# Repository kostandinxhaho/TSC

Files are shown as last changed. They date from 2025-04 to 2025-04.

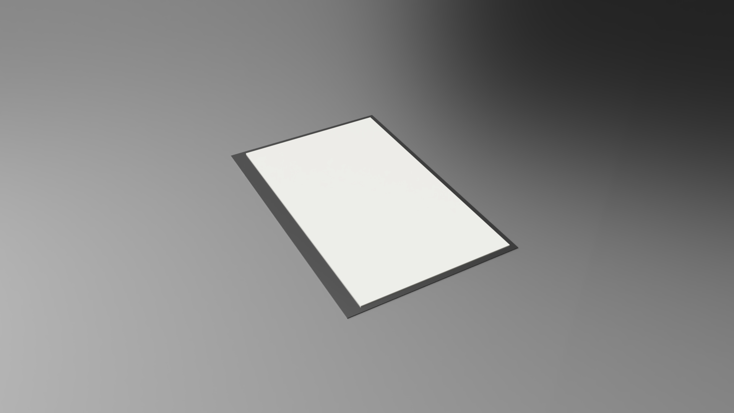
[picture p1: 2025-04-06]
Images/Screen_IMG.jpg

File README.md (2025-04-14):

# OpenBook eReader

This project is a minimalist eBook Reader called **OpenBook**, built around the ESP32-C6 platform. The device is contains:

  - **A 7.5-inch e-paper display**

  - **A Li-Po battery**

  - **USB-C charging**

  - **Navigation buttons**

The design focuses on energy efficiency and ease of use, featuring a simple interface managed via GPIOs. The primary goal is to provide an optimal e-reading experience with low power consumption and a comfortable display.

## System Overview

| **Component** | **Details** |
|---|---|
| **MCU** | ESP32-C6 – supports Wi-Fi 6, BLE, Zigbee, and Thread |
| **Display** | 7.5-inch E-Paper (800 x 480 resolution, ~44g) |
| **Sensors** | BME688 – measures gas, humidity, temperature, and pressure |
| **Storage** | External NOR Flash 64MB (SPI) <br> SD Card (SPI) for extra storage |
| **Power Supply** | Battery: CELLEVIA BATTERIES LP584174 (3.7V, 1800mAh) <br> LDO Voltage Regulator for a steady 3.3V |
| **RTC** | Real-Time Clock for keeping time even when powered off |
| **Charging** | MCP73831T – charges via USB-C |
| **Extras** | Test Pads for debugging <br> Qwiic interface for easy module expansion |

## Block Diagram



## Bill of Materials:
| **Component** | **Purchase Link** | **Datasheet Link** |
|---|---|---|
| 112A-TAAR-R03 ATTEND | [Buy on Digi-Key](https://www.digikey.com/en/products/detail/attend-technology/112A-TAAR-R03/17633923) | [Datasheet](https://www.snapeda.com/parts/112A-TAAR-R03/Attend/datasheet/) |
| BDS229G-TR | [Buy on Digi-Key](https://www.digikey.com/en/products/detail/rohm-semiconductor/BDS229G-TR/3663792) | [Datasheet](https://fscdn.rohm.com/en/products/databook/datasheet/ic/power/voltage_detector/bds229g-e.pdf) |
| ESP32 WROVER BME680 Sensor | [Buy on Mouser](https://www.mouser.com/ProductDetail/Bosch-Sensortec/BME680) | [Datasheet](https://www.bosch-sensortec.com/media/boschsensortec/downloads/datasheets/bst-bme680-ds001.pdf) |
| LED CHG_LED | [Buy on Mouser](https://www.mouser.com/ProductDetail/Wurth-Elektronik/150060SS75000) | [Datasheet](https://www.we-online.com/components/products/datasheet/150060SS75000.pdf) |
| Condensator C0402 | [Buy on Digi-Key](https://www.digikey.com/en/products/detail/murata-electronics/GRM155R71C104KA88D/675947) | [Datasheet](https://search.murata.co.jp/Ceramy/image/img/A01X/G101/ENG/GRM155R71C104KA88-01.pdf) |
| Condensator Tant | [Buy on Digi-Key](https://www.digikey.com/en/products/detail/kemet/T491A106K016AT/2336183) | [Datasheet](https://search.kemet.com/download/datasheet/T491A106K016AT) |
| Q1 DMG2305UX-7 | [Buy on Mouser](https://www.mouser.com/ProductDetail/Diodes-Incorporated/DMG2305UX-7) | [Datasheet](https://www.diodes.com/assets/Datasheets/DMG2305UX.pdf) |
| RTC MODULE DS3231SN# | [Buy on Digi-Key](https://www.digikey.com/en/products/detail/analog-devices-inc-maxim-integrated/DS3231SN/1197576) | [Datasheet](https://www.analog.com/media/en/technical-documentation/data-sheets/DS3231.pdf) |
| ESP32 C6 WROOM-1-N8 | [Buy on Digi-Key](https://www.digikey.com/en/products/detail/espressif-systems/ESP32-C6-WROOM-1-N8/17728866) | [Datasheet](https://www.espressif.com/sites/default/files/documentation/esp32-c6-wroom-1_wroom-1u_datasheet_en.pdf) |
| FH34SRJ-24S-0.5SH(99) | [Buy on Digi-Key](https://www.digikey.com/en/products/detail/hirose-electric-co-ltd/FH34SRJ-24S-0-5SH-99/5132529) | [Datasheet](https://www.hirose.com/product/p/CL0580-1255-6-99) |
| MAX17048G+T10 | [Buy on Mouser](https://www.mouser.com/ProductDetail/Analog-Devices/MAX17048G+T10) | [Datasheet](https://www.analog.com/media/en/technical-documentation/data-sheets/max17048-max17049.pdf) |
| MBR0530 Schottky Diode | [Buy on Mouser](https://www.mouser.com/ProductDetail/onsemi/MBR0530T1G) | [Datasheet](https://www.onsemi.com/pdf/datasheet/mbr0530t1-d.pdf) |
| ESP32 WROVER MCP73831 Power Management | [Buy on Adafruit](https://www.adafruit.com/product/4410) | [Datasheet](https://ww1.microchip.com/downloads/en/DeviceDoc/20001984g.pdf) |
| PFMF.050.1 | [Buy on Mouser](https://www.mouser.com/ProductDetail/Littelfuse/PFMF050-1) | [Datasheet](https://www.littelfuse.com/~/media/electrical/datasheets/resettable-ptcs/littelfuse_ptc_pfmf_datasheet.pdf) |
| PGB1010603MR | [Buy on Mouser](https://www.mouser.com/ProductDetail/Littelfuse/PGB1010603MR) | [Datasheet](https://www.littelfuse.com/~/media/electrical/datasheets/esd_suppressors/littelfuse_esd_supressor_pulse_guard_pgb0603.pdf) |
| QWIIC_RIGHT_ANGLE CONNECTOR | [Buy on SparkFun](https://www.sparkfun.com/products/14427) | [Datasheet](https://www.jst-mfg.com/product/pdf/eng/eSR.pdf) |
| Rezistență R0402 | [Buy on Mouser](https://www.mouser.com/c/passive-components/resistors/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) | [Datasheet](https://www.yageo.com/upload/media/product/product_search/datasheet/cpr/yageo-rc_series_datasheet_2018.pdf) |
| SD0805S020S1R0 | [Buy on Digi-Key](https://www.digikey.com/en/products/detail/littelfuse-inc/SD0805S020S1R0/736561) | [Datasheet](https://www.littelfuse.com/~/media/electrical/datasheets/resettable-ptcs/littelfuse_ptc_sd0805_series.pdf) |
| Si1308EDL-T1-GE3 MOSFET | [Buy on Mouser](https://www.mouser.com/ProductDetail/Vishay/SI1308EDL-T1-GE3) | [Datasheet](https://www.vishay.com/docs/63442/si1308edl.pdf) |
| USB4110-GF-A | [Buy on Mouser](https://www.mouser.com/ProductDetail/GCT/USB4110-GF-A) | [Datasheet](https://gct.co/drawings/usb4110.pdf) |
| USBLC6-2SC6Y | [Buy on Mouser](https://www.mouser.com/ProductDetail/STMicroelectronics/USBLC6-2SC6Y) | [Datasheet](https://www.st.com/resource/en/datasheet/usblc6-2sc6.pdf) |
| W25Q512JVEIQ | [Buy on Mouser](https://www.mouser.com/ProductDetail/Winbond/W25Q512JVEIQ) | [Datasheet](https://www.winbond.com/resource-files/w25q512jv%20revg%2011022019%20plus.pdf) |
| XC6220A331MR-G | [Buy on Digi-Key](https://www.digikey.com/en/products/detail/torex-semiconductor-ltd/XC6220A331MR-G/5027707) | [Datasheet](https://www.torexsemi.com/file/xc6220/XC6220.pdf) |
| 744043680 BOBINA | [Buy on Mouser](https://www.mouser.com/ProductDetail/Wurth-Elektronik/744043680) | [Datasheet](https://katalog.we-online.com/pbs/datasheet/744043680.pdf) |

## Power Supply & Battery Management

The system supports dual power sources:

- **USB-C (5V) input**
- **3.7V Li-Po battery (CELLEVIA LP584174, 1800mAh)**

Power is managed as follows:

- **MCP73831** – Charges the Li-Po battery when USB-C is connected
- **LDO Voltage Regulator** – Converts 5V USB input to 3.3V

##  Sensors & Real-Time Clock (RTC)

Connected via the I²C bus:

- **BME688** – Measures temperature, humidity, pressure, and VOCs
- **DS3231** – High-precision RTC with battery backup

Sensor readings are processed locally and can be used for both display and logging.

## E-Paper Display

The **7.5-inch E-Ink display** interfaces over SPI and is controlled using:

- `EPD_CS` – Chip Select  
- `EPD_DC` – Data/Command  
- `EPD_RST` – Reset  
- `EPD_BUSY` – Busy indicator

The display only consumes energy when refreshing. Once the image is rendered, it holds static content without any power draw — perfect for long battery life.

## ESP32-C6 Connection

The following table shows the core hardware connections between the ESP32-C6 and its peripherals, organized by function:

| **Function** | **ESP32-C6 Pins** |
|---|---|
| **Power & Reset** | 3V3, GND, EN |
| **USB-C** | GPIO13 (USB_D+), GPIO14 (USB_D−) |
| **SD Card (SPI)** | GPIO27 (MISO), GPIO7 (MOSI), GPIO6 (SCK), GPIO4 (SS_SD) |
| **E-Paper Display**  | GPIO11 (EPD_CS), GPIO5 (EPD_DC), GPIO21 (EPD_RST), GPIO26 (EPD_BUSY) |
| **BME688 Sensor (I²C)** | GPIO19 (SDA), GPIO20 (SCL), GPIO17 (I2C_PWR) |
| **UART** | TXD0, RXD0 |
| **External Flash** | FLASH_CS |
| **Other Functions**  | IO/BOOT, RTC_PWM, RTC_RST, INT_RTC |

## Communication Interfaces

- **SPI Bus**: Used by the E-Paper display, external Flash, and SD card. Each device has its own **chip select (CS)** pin to avoid conflicts.
- **I²C Bus**: Shared among BME688, RTC, and battery monitoring. Devices are addressable and use internal pull-ups for signal integrity.
- **UART**: Reserved for programming and serial monitoring via USB.
- **GPIOs**: Dedicated for user interaction (buttons, interrupts) or reserved for future extension.

## The project realization process

- Firstly I built the schematic using the model given in OCW, for the PCB model I followed the scheme respecting the given parameters.
- I created the ground planes with the GND signal on the top and bottom.
- Autorooted the paths, made the cables 0.3mm and 1.5mm respectively. Here I had to keep 1 of the cables the default size of 1.27 because it would create a lot of errors. (AIRCABLE)
- Made the battery and screen 3d models respecting the given parameters. Rendernd all the 3d models and the whole of them combined.

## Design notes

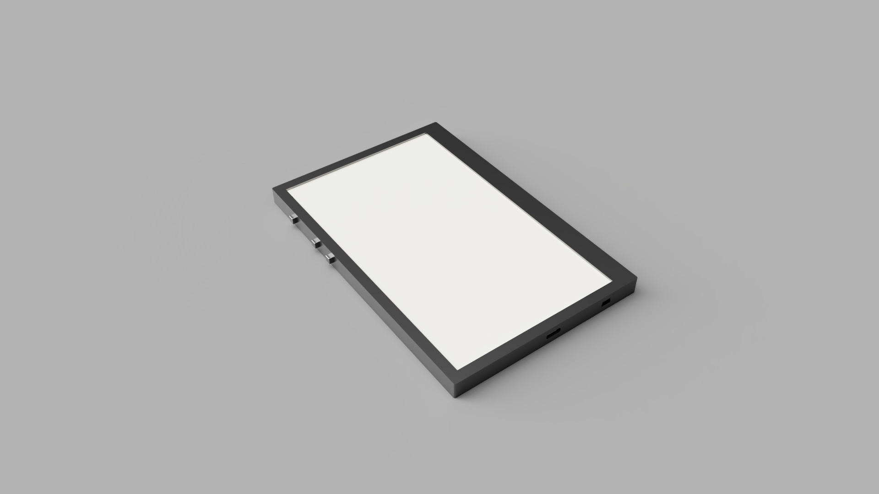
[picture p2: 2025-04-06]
Images/OpenBook_IMG.jpg

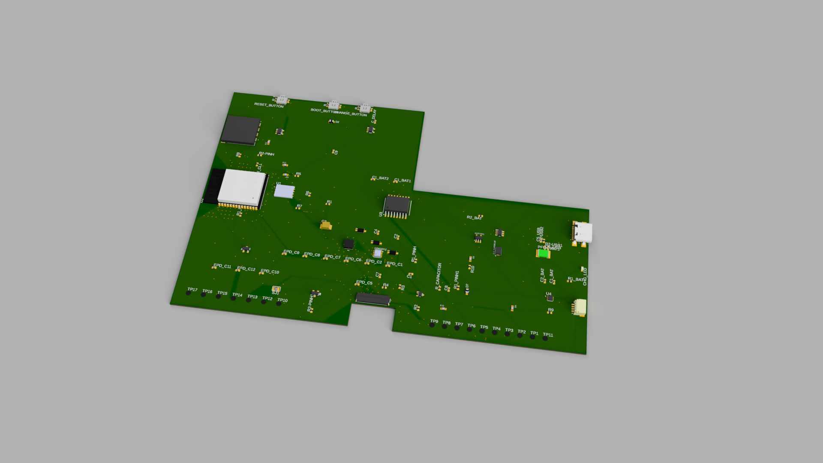
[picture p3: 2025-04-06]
Images/PCB_3D_IMG.jpg

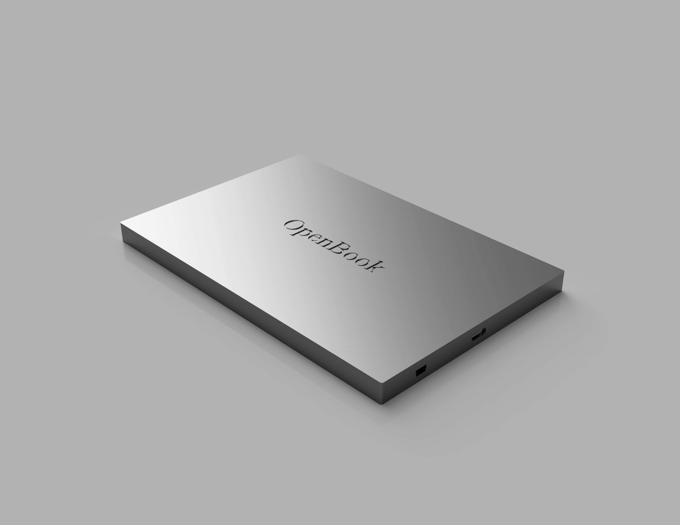
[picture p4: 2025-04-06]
Images/OpenBook_IMG_v2.jpg

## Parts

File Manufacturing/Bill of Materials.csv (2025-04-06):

Part | Value | Device | Package | Description
BOOT_BUTTON | BUTTON_CUSYOMV1 | BUTTON_CUSYOMV1 | MYBUTTON
C1 | 100nF | ESP32_WROVER_EAGLE-LTSPICE_CC0402 | ESP32_WROVER_EAGLE-LTSPICE_C0402 | CAPACITOR, European symbol
C1_BAT | 4.7uF | ESP32_WROVER_EAGLE-LTSPICE_CC0402 | ESP32_WROVER_EAGLE-LTSPICE_C0402 | CAPACITOR, European symbol
C1_BAT1 | 4.7uF | ESP32_WROVER_EAGLE-LTSPICE_CC0402 | ESP32_WROVER_EAGLE-LTSPICE_C0402 | CAPACITOR, European symbol
C1_BAT2 | 4.7uF | ESP32_WROVER_EAGLE-LTSPICE_CC0402 | ESP32_WROVER_EAGLE-LTSPICE_C0402 | CAPACITOR, European symbol
C2 | 100nF | ESP32_WROVER_EAGLE-LTSPICE_CC0402 | ESP32_WROVER_EAGLE-LTSPICE_C0402 | CAPACITOR, European symbol
C2_BAT | 4.7uF | ESP32_WROVER_EAGLE-LTSPICE_CC0402 | ESP32_WROVER_EAGLE-LTSPICE_C0402 | CAPACITOR, European symbol
C3 | 100uF TANT | RCL_CPOL-EUCT3528 | RCL_CT3528 | POLARIZED CAPACITOR, European symbol
C4 | 4.7uF/25V | EAGLE-LTSPICE_CC0402 | EAGLE-LTSPICE_C0402 | CAPACITOR, European symbol
C4_USB | 100nF | EAGLE-LTSPICE_CC0402 | EAGLE-LTSPICE_C0402 | CAPACITOR, European symbol
C5 | 1uF | ESP32_WROVER_EAGLE-LTSPICE_CC0402 | ESP32_WROVER_EAGLE-LTSPICE_C0402 | CAPACITOR, European symbol
C5_USB | 4.7uF | EAGLE-LTSPICE_CC0402 | EAGLE-LTSPICE_C0402 | CAPACITOR, European symbol
C6 | 100nF | ESP32_WROVER_EAGLE-LTSPICE_CC0402 | ESP32_WROVER_EAGLE-LTSPICE_C0402 | CAPACITOR, European symbol
C7 | 10uF | ESP32_WROVER_EAGLE-LTSPICE_CC0402 | ESP32_WROVER_EAGLE-LTSPICE_C0402 | CAPACITOR, European symbol
C8 | 100nF | ESP32_WROVER_EAGLE-LTSPICE_CC0402 | ESP32_WROVER_EAGLE-LTSPICE_C0402 | CAPACITOR, European symbol
C9 | 100nF | ESP32_WROVER_EAGLE-LTSPICE_CC0402 | ESP32_WROVER_EAGLE-LTSPICE_C0402 | CAPACITOR, European symbol
C10 | 100nF | ESP32_WROVER_EAGLE-LTSPICE_CC0402 | ESP32_WROVER_EAGLE-LTSPICE_C0402 | CAPACITOR, European symbol
C10_SUPERCAP | CPH3225A | CPH3225A | CAPCP3225X100N | Cap 0.011F 3.3V 1210 Flat Check availability
CHANGE_BUTTON | BUTTON_CUSYOMV1 | BUTTON_CUSYOMV1 | MYBUTTON
CHG_LED |  | ADAFRUIT_LEDCHIP-LED0603 | ADAFRUIT_CHIP-LED0603 | LED
C_DELAY | 100nF | ESP32_WROVER_EAGLE-LTSPICE_CC0402 | ESP32_WROVER_EAGLE-LTSPICE_C0402 | CAPACITOR, European symbol
D1 | USBLC6-2SC6Y | USBLC6-2SC6Y | SOT95P280X145-6N | Low Cap. ESD Protection Auto SOT-23-6 STMicroelectronics USBLC6-2SC6Y, Dual Uni-Directional TVS Diode Array, 6-Pin SOT-23
D2 | ESP32_WROVER_AVX---SD0805S020S1R0_AVX_SD0805S020S1R0_0_0AVX_SD0805S020S1R0_0_0 | ESP32_WROVER_AVX---SD0805S020S1R0_AVX_SD0805S020S1R0_0_0AVX_SD0805S020S1R0_0_0 | ESP32_WROVER_AVX---SD0805S020S1R0_AVX_SD0805S020S1R0_0 | Schottky Barrier Rectifier Diode
D3 | MBR0530 | MBR0530 | SOD3716X135N | ON SEMICONDUCTOR - MBR0530 - DIODE, SCHOTTKY, 0.5A, 30V, SOD-123
D4 | MBR0530 | MBR0530 | SOD3716X135N | ON SEMICONDUCTOR - MBR0530 - DIODE, SCHOTTKY, 0.5A, 30V, SOD-123
D5 | MBR0530 | MBR0530 | SOD3716X135N | ON SEMICONDUCTOR - MBR0530 - DIODE, SCHOTTKY, 0.5A, 30V, SOD-123
D6 | PGB1010603MR | PGB1010603MR | DIOC1608X36N | Check availability
D7 | ESP32_WROVER_AVX---SD0805S020S1R0_AVX_SD0805S020S1R0_0_0AVX_SD0805S020S1R0_0_0 | ESP32_WROVER_AVX---SD0805S020S1R0_AVX_SD0805S020S1R0_0_0AVX_SD0805S020S1R0_0_0 | ESP32_WROVER_AVX---SD0805S020S1R0_AVX_SD0805S020S1R0_0 | Schottky Barrier Rectifier Diode
D8 | PGB1010603MR | PGB1010603MR | DIOC1608X36N | Check availability
D9 | PGB1010603MR | PGB1010603MR | DIOC1608X36N | Check availability
D10 | PGB1010603MR | PGB1010603MR | DIOC1608X36N | Check availability
D11 | PGB1010603MR | PGB1010603MR | DIOC1608X36N | Check availability
D12 | PGB1010603MR | PGB1010603MR | DIOC1608X36N | Check availability
EPD_C1 | 1uF/50V | ESP32_WROVER_EAGLE-LTSPICE_CC0402 | ESP32_WROVER_EAGLE-LTSPICE_C0402 | CAPACITOR, European symbol
EPD_C2 | 1uF/50V | ESP32_WROVER_EAGLE-LTSPICE_CC0402 | ESP32_WROVER_EAGLE-LTSPICE_C0402 | CAPACITOR, European symbol
EPD_C5 | 0.1uF/50V | ESP32_WROVER_EAGLE-LTSPICE_CC0402 | ESP32_WROVER_EAGLE-LTSPICE_C0402 | CAPACITOR, European symbol
EPD_C6 | 1uF/50V | ESP32_WROVER_EAGLE-LTSPICE_CC0402 | ESP32_WROVER_EAGLE-LTSPICE_C0402 | CAPACITOR, European symbol
EPD_C7 | 1uF/50V | ESP32_WROVER_EAGLE-LTSPICE_CC0402 | ESP32_WROVER_EAGLE-LTSPICE_C0402 | CAPACITOR, European symbol
EPD_C8 | 1uF/50V | ESP32_WROVER_EAGLE-LTSPICE_CC0402 | ESP32_WROVER_EAGLE-LTSPICE_C0402 | CAPACITOR, European symbol
EPD_C9 | 1uF/50V | ESP32_WROVER_EAGLE-LTSPICE_CC0402 | ESP32_WROVER_EAGLE-LTSPICE_C0402 | CAPACITOR, European symbol
EPD_C10 | 1uF/50V | ESP32_WROVER_EAGLE-LTSPICE_CC0402 | ESP32_WROVER_EAGLE-LTSPICE_C0402 | CAPACITOR, European symbol
EPD_C11 | 1uF/50V | ESP32_WROVER_EAGLE-LTSPICE_CC0402 | ESP32_WROVER_EAGLE-LTSPICE_C0402 | CAPACITOR, European symbol
EPD_C12 | 1uF/50V | ESP32_WROVER_EAGLE-LTSPICE_CC0402 | ESP32_WROVER_EAGLE-LTSPICE_C0402 | CAPACITOR, European symbol
IC1 | BD5229G-TR | BD5229G-TR | SOT95P280X125-5N | Voltage Detector with Adjustable Delay Time: CMOS processes are utilized to develop high precision, low current consumption CMOS reset ICs that allow arbitrary setting of the delay time. The extensive lineup includes both Nch Open Drain and CMOS output types in a wide range of detection voltages (from 2.3V to 6.0V, in 0.1V steps), enabling selection of the ideal solution based on customer requirements. In addition, the entire series is of course both lead-free and RoHS-compliant.
IC4 | XC6220A331MR-G | XC6220A331MR-G | SOT95P280X120-5N | LDO Voltage Regulators
J1 | FH34SRJ-24S-0.5SH_99_ | FH34SRJ-24S-0.5SH_99_ | FH34SRJ24S05SH99 | (0.50mm) Surface Mount, Right Angle
J2 | SAMACSYS_PARTS_USB4110-GF-A | SAMACSYS_PARTS_USB4110-GF-A | SAMACSYS_PARTS_USB4110GFA | CONN USB 2.0 TYPE-C R/A SMT
J3 | QWIIC_RIGHT_ANGLE | QWIIC_CONNECTORJS-1MM | JST04_1MM_RA | SparkFun I2C Standard Qwiic Connector
J4 | 112A-TAAR-R03_ATTEND | 112A-TAAR-R03_ATTEND | 112ATAARR03ATTEND | Micro SD Card Socket, Push-Push Type, Top Mount, SMT, H=1.83mm, 10u
L1 | 68uH | 744043680IND_4828-WE-TPC_WRE | IND_4828-WE-TPC_WRE
MCP73831 | ESP32_WROVER_SPARKFUN-IC-POWER_MCP73831 | ESP32_WROVER_SPARKFUN-IC-POWER_MCP73831 | ESP32_WROVER_SPARKFUN-IC-POWER_SOT23-5 | MCP73831T Li-Ion, Li-Pol Controller
PFMF.050.1 | ESP32C6_VARISTORCN1812 | ESP32C6_VARISTORCN1812 | ESP32C6_VARISTOR_CT/CN1812 | VARISTOR
Q1 | 20V/4.2A/52mO/1.4W | ESP32_WROVER_SPARKFUN-DISCRETESEMI_MOSFET_PCH-DMG2305UX-7 | ESP32_WROVER_SPARKFUN-DISCRETESEMI_SOT23-3 | P-channel MOSFETs
Q2 | 20V/4.2A/52mO/1.4W | ESP32_WROVER_SPARKFUN-DISCRETESEMI_MOSFET_PCH-DMG2305UX-7 | ESP32_WROVER_SPARKFUN-DISCRETESEMI_SOT23-3 | P-channel MOSFETs
Q3 | SI1308EDL-T1-GE3 | SI1308EDL-T1-GE3 | SOT65P210X110-3N | MOSFET N-Ch 30V 1.5A TrenchFET SC70 Vishay Si1308EDL-T1-GE3 N-channel MOSFET Transistor, 1.5 A, 30 V, 3-Pin SC-70
R1 | 10K | ESP32_WROVER_EAGLE-LTSPICE_RR0402 | ESP32_WROVER_EAGLE-LTSPICE_R0402 | RESISTOR, European symbol
R1_BAT | 200 | ESP32_WROVER_EAGLE-LTSPICE_RR0402 | ESP32_WROVER_EAGLE-LTSPICE_R0402 | RESISTOR, European symbol
R1_PINH | 10K | ESP32_WROVER_EAGLE-LTSPICE_RR0402 | ESP32_WROVER_EAGLE-LTSPICE_R0402 | RESISTOR, European symbol
R1_PINH1 | 10K | ESP32_WROVER_EAGLE-LTSPICE_RR0402 | ESP32_WROVER_EAGLE-LTSPICE_R0402 | RESISTOR, European symbol
R1_PWRUSB | 100K | ESP32_WROVER_EAGLE-LTSPICE_RR0402 | ESP32_WROVER_EAGLE-LTSPICE_R0402 | RESISTOR, European symbol
R2 | 2.2 | ESP32_WROVER_EAGLE-LTSPICE_RR0402 | ESP32_WROVER_EAGLE-LTSPICE_R0402 | RESISTOR, European symbol
R2-PINH | 10K | ESP32_WROVER_EAGLE-LTSPICE_RR0402 | ESP32_WROVER_EAGLE-LTSPICE_R0402 | RESISTOR, European symbol
R2-PINH1 | 10K | ESP32_WROVER_EAGLE-LTSPICE_RR0402 | ESP32_WROVER_EAGLE-LTSPICE_R0402 | RESISTOR, European symbol
R2-USB1 | 5k1 | ESP32_WROVER_EAGLE-LTSPICE_RR0402 | ESP32_WROVER_EAGLE-LTSPICE_R0402 | RESISTOR, European symbol
R2-USB2 | 5k1 | ESP32_WROVER_EAGLE-LTSPICE_RR0402 | ESP32_WROVER_EAGLE-LTSPICE_R0402 | RESISTOR, European symbol
R2_BAT | 2K | ESP32_WROVER_EAGLE-LTSPICE_RR0402 | ESP32_WROVER_EAGLE-LTSPICE_R0402 | RESISTOR, European symbol
R3 | 0.47 | ESP32_WROVER_EAGLE-LTSPICE_RR0402 | ESP32_WROVER_EAGLE-LTSPICE_R0402 | RESISTOR, European symbol
R4 | 10K | ESP32_WROVER_EAGLE-LTSPICE_RR0402 | ESP32_WROVER_EAGLE-LTSPICE_R0402 | RESISTOR, European symbol
R5 | 10K | ESP32_WROVER_EAGLE-LTSPICE_RR0402 | ESP32_WROVER_EAGLE-LTSPICE_R0402 | RESISTOR, European symbol
R6 | 10K | ESP32_WROVER_EAGLE-LTSPICE_RR0402 | ESP32_WROVER_EAGLE-LTSPICE_R0402 | RESISTOR, European symbol
R7 | 10K | ESP32_WROVER_EAGLE-LTSPICE_RR0402 | ESP32_WROVER_EAGLE-LTSPICE_R0402 | RESISTOR, European symbol
R8 | 10K | ESP32_WROVER_EAGLE-LTSPICE_RR0402 | ESP32_WROVER_EAGLE-LTSPICE_R0402 | RESISTOR, European symbol
R9 | 10K | ESP32_WROVER_EAGLE-LTSPICE_RR0402 | ESP32_WROVER_EAGLE-LTSPICE_R0402 | RESISTOR, European symbol
R10 | 10K | ESP32_WROVER_EAGLE-LTSPICE_RR0402 | ESP32_WROVER_EAGLE-LTSPICE_R0402 | RESISTOR, European symbol
RESET_BUTTON | BUTTON_CUSYOMV1 | BUTTON_CUSYOMV1 | MYBUTTON
R_BOOT | 10K | ESP32_WROVER_EAGLE-LTSPICE_RR0402 | ESP32_WROVER_EAGLE-LTSPICE_R0402 | RESISTOR, European symbol
R_CAPACITOR | 15 | ESP32_WROVER_EAGLE-LTSPICE_RR0402 | ESP32_WROVER_EAGLE-LTSPICE_R0402 | RESISTOR, European symbol
R_CHANGE | 10K | ESP32_WROVER_EAGLE-LTSPICE_RR0402 | ESP32_WROVER_EAGLE-LTSPICE_R0402 | RESISTOR, European symbol
R_CL1 | 10K | ESP32_WROVER_EAGLE-LTSPICE_RR0402 | ESP32_WROVER_EAGLE-LTSPICE_R0402 | RESISTOR, European symbol
R_RESET | 10K | ESP32_WROVER_EAGLE-LTSPICE_RR0402 | ESP32_WROVER_EAGLE-LTSPICE_R0402 | RESISTOR, European symbol
SENSOR2 | BME688 | ESP32_WROVER_BME680_BME680 | ESP32_WROVER_BME680_PSON80P300X300X100-8N | Integrated Environmental Unit
SJ1 |  | SJ | SJ | SMD solder JUMPER
TP1 | TPTP20R | TPTP20R | TP20R | Test pad
TP2 | TPTP20R | TPTP20R | TP20R | Test pad
TP3 | TPTP20R | TPTP20R | TP20R | Test pad
TP4 | TPTP20R | TPTP20R | TP20R | Test pad
TP5 | TPTP20R | TPTP20R | TP20R | Test pad
TP6 | TPTP20R | TPTP20R | TP20R | Test pad
TP7 | TPTP20R | TPTP20R | TP20R | Test pad
TP8 | TPTP20R | TPTP20R | TP20R | Test pad
TP9 | TPTP20R | TPTP20R | TP20R | Test pad
TP10 | TPTP20R | TPTP20R | TP20R | Test pad
TP11 | TPTP20R | TPTP20R | TP20R | Test pad
TP12 | TPTP20R | TPTP20R | TP20R | Test pad
TP13 | TPTP20R | TPTP20R | TP20R | Test pad
TP14 | TPTP20R | TPTP20R | TP20R | Test pad
TP15 | TPTP20R | TPTP20R | TP20R | Test pad
TP16 | TPTP20R | TPTP20R | TP20R | Test pad
TP17 | TPTP20R | TPTP20R | TP20R | Test pad
U1 | W25Q512JVEIQ | W25Q512JVEIQ | SON127P600X800X80-9N | Check availability
U2 | ESP32-C6-WROOM-1-N8 | ESP32-C6-WROOM-1-N8 | XCVR_ESP32-C6-WROOM-1-N8 | Check availability
U3 | DS3231SN# | DS3231SN# | SOIC127P1032X265-16N | Real Time Clock Serial 16-Pin SOIC W T/R Check availability
U4 | MAX17048G+T10 | MAX17048G+T10 | SON50P200X200X80-9N | Check availability

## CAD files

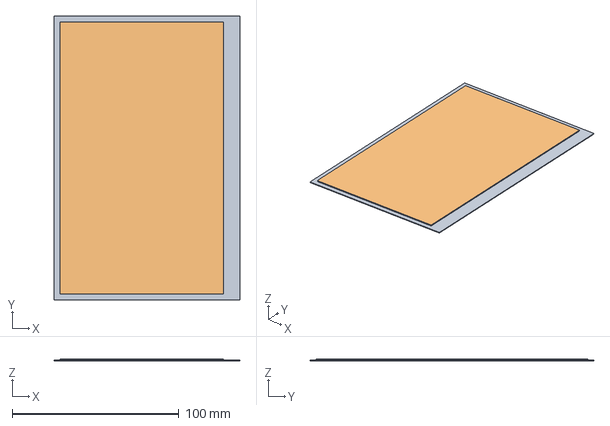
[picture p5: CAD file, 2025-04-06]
Mechanical/Screen.step
111.2 x 170.2 x 1.18 mm

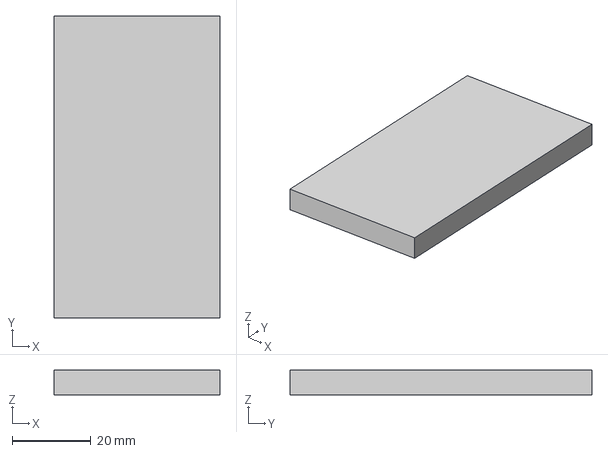
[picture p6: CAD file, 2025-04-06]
Mechanical/Battery.step
42.0 x 76.5 x 6.30 mm

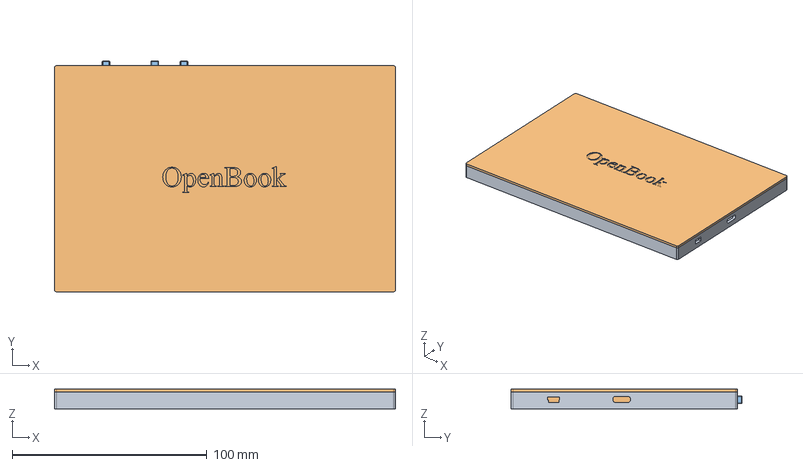
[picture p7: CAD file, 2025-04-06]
Mechanical/OpenBook_case.step
175.2 x 118.5 x 10.2 mm

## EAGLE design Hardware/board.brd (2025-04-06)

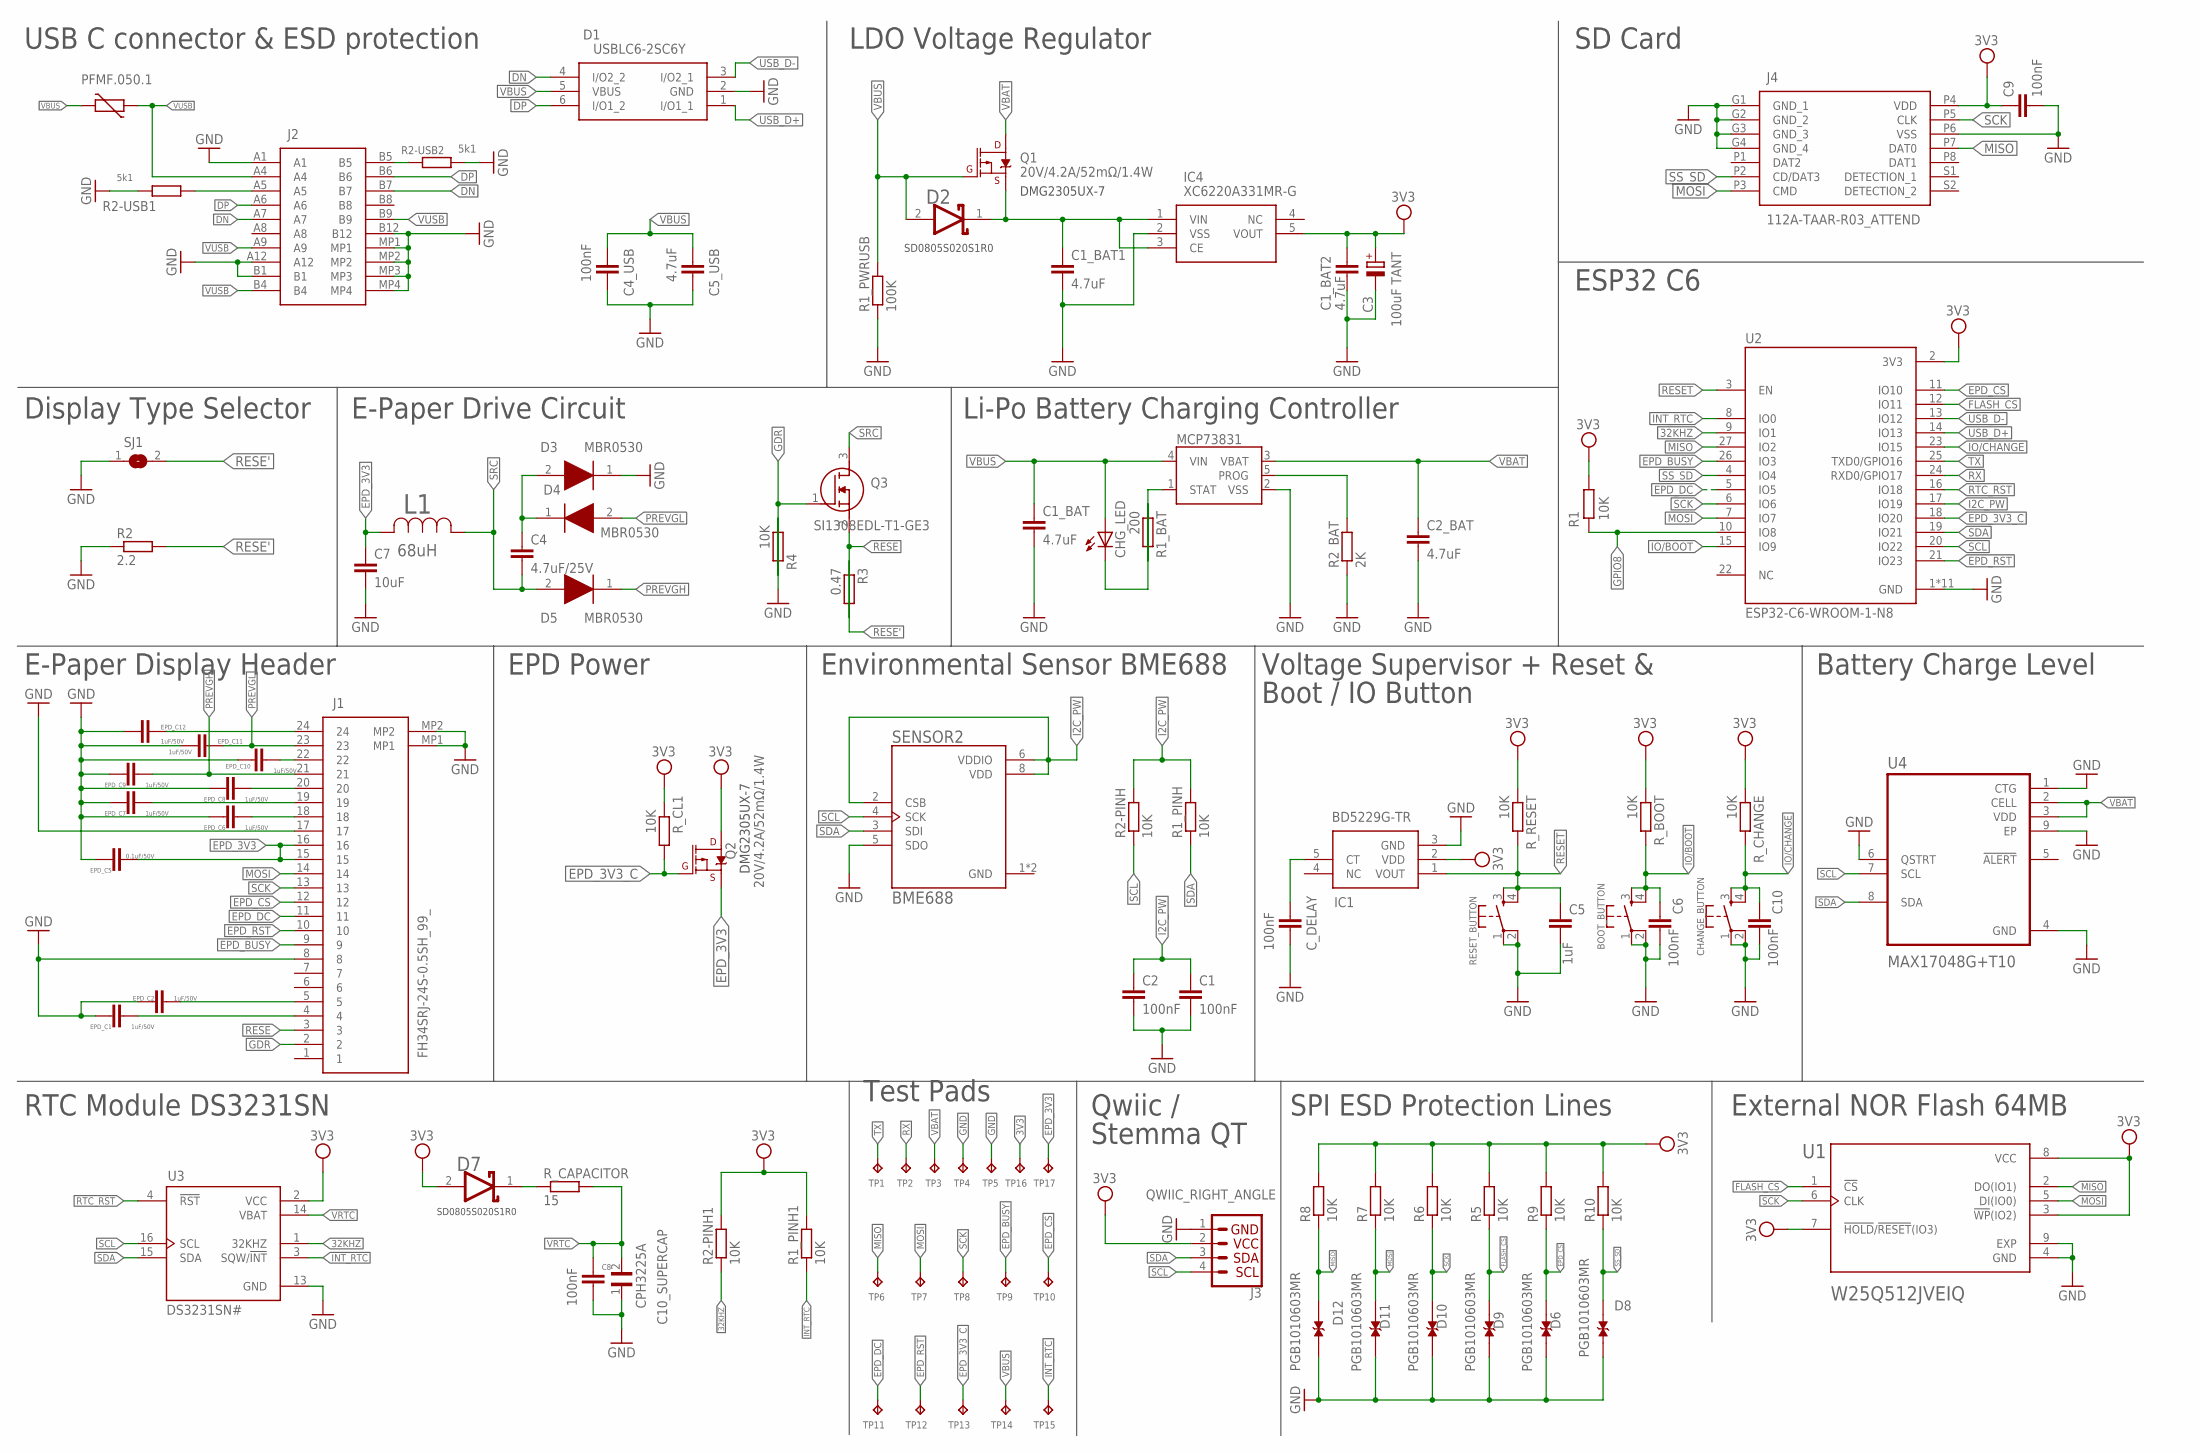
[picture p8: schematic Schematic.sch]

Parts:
BOOT_BUTTON: BUTTON_CUSYOMV1; MYBUTTON
C1, C2, C6, C8, C9, C10: 100nF; ESP32_WROVER_EAGLE-LTSPICE_C0402
C1_BAT, C1_BAT1, C1_BAT2, C2_BAT: 4.7uF; ESP32_WROVER_EAGLE-LTSPICE_C0402
C3: 100uF TANT; RCL_CT3528
C4: 4.7uF/25V; EAGLE-LTSPICE_C0402
C4_USB: 100nF; EAGLE-LTSPICE_C0402
C5: 1uF; ESP32_WROVER_EAGLE-LTSPICE_C0402
C5_USB: 4.7uF; EAGLE-LTSPICE_C0402
C7: 10uF; ESP32_WROVER_EAGLE-LTSPICE_C0402
C10_SUPERCAP: CPH3225A; CAPCP3225X100N
CHANGE_BUTTON: BUTTON_CUSYOMV1; MYBUTTON
CHG_LED: ADAFRUIT_LEDCHIP-LED0603; ADAFRUIT_CHIP-LED0603
C_DELAY: 100nF; ESP32_WROVER_EAGLE-LTSPICE_C0402
D1: USBLC6-2SC6Y; SOT95P280X145-6N
D2, D7: ESP32_WROVER_AVX---SD0805S020S1R0_AVX_SD0805S020S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; ESP32_WROVER_AVX---SD0805S020S1R0_AVX_SD0805S020S1R0_0
D3, D4, D5: MBR0530; SOD3716X135N
D6, D8, D9, D10, D11, D12: PGB1010603MR; DIOC1608X36N
EPD_C1, EPD_C2, EPD_C6, EPD_C7, EPD_C8, EPD_C9, EPD_C10, EPD_C11, EPD_C12: 1uF/50V; ESP32_WROVER_EAGLE-LTSPICE_C0402
EPD_C5: 0.1uF/50V; ESP32_WROVER_EAGLE-LTSPICE_C0402
IC1: BD5229G-TR; SOT95P280X125-5N
IC4: XC6220A331MR-G; SOT95P280X120-5N
J1: FH34SRJ-24S-0.5SH_99_; FH34SRJ24S05SH99
J2: SAMACSYS_PARTS_USB4110-GF-A; SAMACSYS_PARTS_USB4110GFA
J3: QWIIC_RIGHT_ANGLE; JST04_1MM_RA
J4: 112A-TAAR-R03_ATTEND; 112ATAARR03ATTEND
L1: 68uH; IND_4828-WE-TPC_WRE
MCP73831: ESP32_WROVER_SPARKFUN-IC-POWER_MCP73831; ESP32_WROVER_SPARKFUN-IC-POWER_SOT23-5
PFMF.050.1: ESP32C6_VARISTORCN1812; ESP32C6_VARISTOR_CT/CN1812
Q1, Q2: 20V/4.2A/52mΩ/1.4W; ESP32_WROVER_SPARKFUN-DISCRETESEMI_SOT23-3
Q3: SI1308EDL-T1-GE3; SOT65P210X110-3N
R1, R1_PINH, R1_PINH1, R2-PINH, R2-PINH1, R4, R5, R6, R7, R8, R9, R10: 10K; ESP32_WROVER_EAGLE-LTSPICE_R0402
R1_BAT: 200; ESP32_WROVER_EAGLE-LTSPICE_R0402
R1_PWRUSB: 100K; ESP32_WROVER_EAGLE-LTSPICE_R0402
R2: 2.2; ESP32_WROVER_EAGLE-LTSPICE_R0402
R2-USB1, R2-USB2: 5k1; ESP32_WROVER_EAGLE-LTSPICE_R0402
R2_BAT: 2K; ESP32_WROVER_EAGLE-LTSPICE_R0402
R3: 0.47; ESP32_WROVER_EAGLE-LTSPICE_R0402
RESET_BUTTON: BUTTON_CUSYOMV1; MYBUTTON
R_BOOT: 10K; ESP32_WROVER_EAGLE-LTSPICE_R0402
R_CAPACITOR: 15; ESP32_WROVER_EAGLE-LTSPICE_R0402
R_CHANGE: 10K; ESP32_WROVER_EAGLE-LTSPICE_R0402
R_CL1: 10K; ESP32_WROVER_EAGLE-LTSPICE_R0402
R_RESET: 10K; ESP32_WROVER_EAGLE-LTSPICE_R0402
SENSOR2: BME688; ESP32_WROVER_BME680_PSON80P300X300X100-8N
SJ1: SJ
TP1, TP2, TP3, TP4, TP5, TP6, TP7, TP8, TP9, TP10, TP11, TP12, TP13, TP14, TP15, TP16, TP17: TPTP20R; TP20R
U1: W25Q512JVEIQ; SON127P600X800X80-9N
U2: ESP32-C6-WROOM-1-N8; XCVR_ESP32-C6-WROOM-1-N8
U3: DS3231SN#; SOIC127P1032X265-16N
U4: MAX17048G+T10; SON50P200X200X80-9N

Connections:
3V3: C1_BAT2.1, C3.+, C9.1, D7.2 (ANODE), IC1.2 (VDD), IC4.5 (VOUT), J3.2, J4.P4 (VDD), Q2.3 (D), R1.1, R1_PINH1.2, R2-PINH1.2, R5.2, R6.2, R7.2, R8.2, R9.2, R10.2, R_BOOT.1, R_CHANGE.1, R_CL1.1, R_RESET.1, TP16.TP, U1.3 (!WP!(IO2)), U1.7 (!HOLD!/!RESET!(IO3)), U1.8 (VCC), U2.2 (3V3), U3.2 (VCC)
32KHZ: R2-PINH1.1, U2.9 (IO1), U3.1 (32KHZ)
DN: D1.4 (I/O2_2), J2.A7, J2.B7
DP: D1.6 (I/O1_2), J2.A6, J2.B6
EPD_3V3: C7.1, EPD_C5.1, J1.15, J1.16, L1.2, Q2.2 (S), TP17.TP
EPD_3V3_C: Q2.1 (G), R_CL1.2, TP13.TP, U2.18 (IO20)
EPD_BUSY: J1.9, TP9.TP, U2.26 (IO3)
EPD_CS: D6.2, J1.12, R9.1, TP10.TP, U2.11 (IO10)
EPD_DC: J1.11, TP11.TP, U2.5 (IO5)
EPD_RST: J1.10, TP12.TP, U2.21 (IO23)
FLASH_CS: D9.2, R5.1, U1.1 (!CS), U2.12 (IO11)
GDR: J1.2, Q3.1 (G), R4.2
GND: BOOT_BUTTON.1, BOOT_BUTTON.2, C1.2, C1_BAT.2, C1_BAT1.2, C1_BAT2.2, C2.2, C2_BAT.2, C3.-, C4_USB.2, C5.2, C5_USB.2, C6.2, C7.2, C8.2, C9.2, C10.2, C10_SUPERCAP.1, CHANGE_BUTTON.1, CHANGE_BUTTON.2, C_DELAY.2, D3.1 (K), D6.1, D8.1, D9.1, D10.1, D11.1, D12.2, EPD_C1.2, EPD_C2.2, IC1.3 (GND), IC4.2 (VSS), J1.8, J1.17, J1.MP1, J1.MP2, J2.A1, J2.A12, J2.B1, J2.B12, J2.MP1, J2.MP2, J2.MP3, J2.MP4, J3.1, J4.G1 (GND_1), J4.G2 (GND_2), J4.G3 (GND_3), J4.G4 (GND_4), J4.P6 (VSS), MCP73831.2 (VSS), R1_PWRUSB.1, R2.1, R2-USB1.1, R2-USB2.2, R2_BAT.1, R4.1, RESET_BUTTON.1, RESET_BUTTON.2, SENSOR2.1 (GND), SENSOR2.5 (SDO), SENSOR2.7 (GND), SJ1.1, TP4.TP, TP5.TP, U1.4 (GND), U1.9 (EXP), U2.1 (GND), U2.28 (GND), U2.29_1 (GND), U2.29_2 (GND), U2.29_3 (GND), U2.29_4 (GND), U2.29_5 (GND), U2.29_6 (GND), U2.29_7 (GND), U2.29_8 (GND), U2.29_9 (GND), U3.13 (GND), U4.1 (CTG), U4.4 (GND), U4.6 (QSTRT), U4.9 (EP)
GPIO8: R1.2, U2.10 (IO8)
I2C_PW: C1.1, C2.1, R1_PINH.2, R2-PINH.2, SENSOR2.2 (CSB), SENSOR2.6 (VDDIO), SENSOR2.8 (VDD), U2.17 (IO19)
INT_RTC: R1_PINH1.1, TP15.TP, U2.8 (IO0), U3.3 (SQW/!INT)
IO/BOOT: BOOT_BUTTON.3, BOOT_BUTTON.4, C6.1, R_BOOT.2, U2.15 (IO9)
IO/CHANGE: C10.1, CHANGE_BUTTON.3, CHANGE_BUTTON.4, R_CHANGE.2, U2.23 (IO15)
MISO: D12.1, J4.P7 (DAT0), R8.1, TP6.TP, U1.2 (DO(IO1)), U2.27 (IO2)
MOSI: D11.2, J1.14, J4.P3 (CMD), R7.1, TP7.TP, U1.5 (DI(IO0)), U2.7 (IO7)
unnamed: J2.A5, R2-USB1.2
unnamed: J2.B5, R2-USB2.1
unnamed: C1_BAT1.1, D2.1 (CATHODE), IC4.1 (VIN), IC4.3 (CE), Q1.2 (S)
unnamed: C4.1, D3.2 (A), D4.1 (K)
unnamed: MCP73831.5 (PROG), R2_BAT.2
unnamed: MCP73831.1 (STAT), R1_BAT.2
unnamed: CHG_LED.C, R1_BAT.1
unnamed: EPD_C12.1, J1.24
unnamed: C_DELAY.1, IC1.5 (CT)
unnamed: EPD_C10.1, J1.22
unnamed: EPD_C6.1, J1.18
unnamed: EPD_C5.2, EPD_C6.2, EPD_C7.2, EPD_C8.2, EPD_C9.2, EPD_C10.2, EPD_C11.2, EPD_C12.2
unnamed: EPD_C7.1, J1.19
unnamed: EPD_C8.1, J1.20
unnamed: D7.1 (CATHODE), R_CAPACITOR.1
unnamed: EPD_C2.1, J1.5
unnamed: EPD_C1.1, J1.4
PREVGH: D5.1 (K), EPD_C9.1, J1.21
PREVGL: D4.2 (A), EPD_C11.1, J1.23
RESE: J1.3, Q3.2 (S), R3.2
RESE': R2.2, R3.1, SJ1.2
RESET: C5.1, IC1.1 (VOUT), RESET_BUTTON.3, RESET_BUTTON.4, R_RESET.2, U2.3 (EN)
RTC_RST: U2.16 (IO18), U3.4 (!RST)
RX: TP2.TP, U2.24 (RXD0/GPIO17)
SCK: D10.2, J1.13, J4.P5 (CLK), R6.1, TP8.TP, U1.6 (CLK), U2.6 (IO6)
SCL: J3.4, R2-PINH.1, SENSOR2.4 (SCK), U2.20 (IO22), U3.16 (SCL), U4.7 (SCL)
SDA: J3.3, R1_PINH.1, SENSOR2.3 (SDI), U2.19 (IO21), U3.15 (SDA), U4.8 (SDA)
SRC: C4.2, D5.2 (A), L1.1, Q3.3 (D)
SS_SD: D8.2, J4.P2 (CD/DAT3), R10.1, U2.4 (IO4)
TX: TP1.TP, U2.25 (TXD0/GPIO16)
USB_D+: D1.1 (I/O1_1), U2.14 (IO13)
USB_D-: D1.3 (I/O2_1), U2.13 (IO12)
VBAT: C2_BAT.1, MCP73831.3 (VBAT), Q1.3 (D), TP3.TP, U4.2 (CELL), U4.3 (VDD)
VBUS: C1_BAT.1, C4_USB.1, C5_USB.1, CHG_LED.A, D1.5 (VBUS), D2.2 (ANODE), MCP73831.4 (VIN), PFMF.050.1.2, Q1.1 (G), R1_PWRUSB.2, TP14.TP
VRTC: C8.1, C10_SUPERCAP.2, R_CAPACITOR.2, U3.14 (VBAT)
VUSB: J2.A4, J2.A9, J2.B4, J2.B9, PFMF.050.1.1

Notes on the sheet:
SD0805S020S1R0
DMG2305UX-7
USB C connector & ESD protection
LDO Voltage Regulator
SD Card
Display Type Selector
E-Paper Drive Circuit
Li-Po Battery Charging Controller
ESP32 C6
E-Paper Display Header
EPD Power
Environmental Sensor BME688
Voltage Supervisor + Reset &
Boot / IO Button
Battery Charge Level
RTC Module DS3231SN
Test Pads
Qwiic /
Stemma QT
SPI ESD Protection Lines
External NOR Flash 64MB

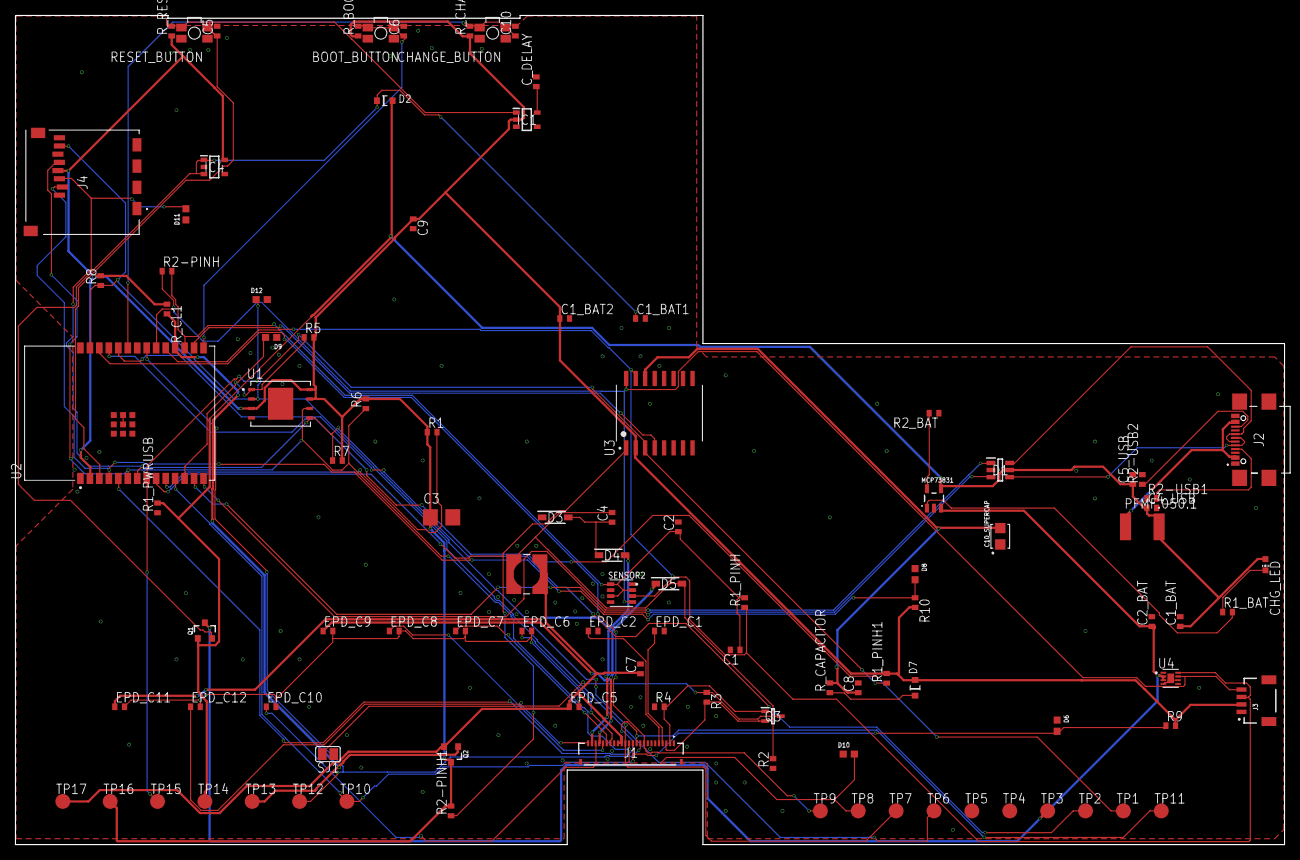
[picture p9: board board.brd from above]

Board: 2 copper layers, 170.2 x 111.2 mm, 103 parts (0 on the bottom side), 56 nets.

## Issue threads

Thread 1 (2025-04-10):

Missing/ incomplete details in the README

anafedeles, 2025-04-10:
The README is missing the system diagram. In the Bill of Materials (BOM), you should include two columns: one with a link to where each component can be purchased, and another with a link to its datasheet which (this is the one that you don't have) . For the ESP32 pins, consider adding a more detailed and clear description of how each pin is used in the project.

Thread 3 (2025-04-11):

Errors and warnings in the schematic

anafedeles, 2025-04-11:
There are several errors and warnings present in the schematic. Some of the connections haven't been made properly — a few nets are either floating or not connected as expected. You should review the schematic and rewire the problematic areas to ensure all components are correctly linked.

Recommendation:
Use the Electrical Rule Check (ERC) tool in your schematic editor to identify and fix all connection issues. Double-check junction dots, overlapping wires, and ensure each net is properly routed to its destination.

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

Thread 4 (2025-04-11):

Board issues

anafedeles, 2025-04-11:
Following my analysis of the PCB section, there are several important aspects that require revision before the design can proceed.

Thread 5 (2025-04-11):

Missing cut under antenna

anafedeles, 2025-04-11:
The area directly underneath the antenna should be cutout. This cutout prevents signal reflections and improves the overall efficiency of the wireless communication.
To implement this, use an outline polyline to define the area that needs to be cleared.

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

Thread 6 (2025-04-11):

Missing drawn dimensions on the PCB

anafedeles, 2025-04-11:
You should include the dimensions as specified in the OCW file. Please make sure to trace the dimensions accurately and place them on the appropriate layer, as defined in the design rules.

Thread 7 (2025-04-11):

Incorrect power and signal trace widths

anafedeles, 2025-04-11:
The current power traces (VUSB, VBUS, 3V3, etc.) are not conform to the required width of 0.3 mm as per the design constraints.

To address this:
1. Create a new net class in the Design Manager, give it a name(e.g.: POWER) and assign the relevant power nets (VUSB, VBUS, 3V3, etc.) to it.
2. Set up a custom rule for this net class to enforce a minimum trace width of 0.3 mm.
3. Apply the correct trace width before continuing with the final routing.

Also, adjust the copper width to 0.15 mm.

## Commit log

2025-04-06 Firt commit
    [Schematic.sch, board.brd]
2025-04-06 Finished 70%
    [Battery.step, Bill of Materials.csv, OpenBook_case.step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]

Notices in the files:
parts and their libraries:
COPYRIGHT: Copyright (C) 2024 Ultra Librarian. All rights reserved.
